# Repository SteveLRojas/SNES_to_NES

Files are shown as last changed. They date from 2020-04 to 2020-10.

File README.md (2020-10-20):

# SNES_to_NES
This project is an adapter board designed to be installed inside a SNES gamepad.  
The source is written in assembly for the AT90S1200 MCU. All code is in the main ASM file.  
All the project details can be inferred from the source file, which is short, simple, and well commented.  
A single layer PCB design is included.  

Bug fix: added temporary nes variable in main. This is need so that the NES variable is always valid, as the NES console can trigger an interrupt and read it at any time.  
	In previous versions the A and B buttons had a small chance of getting pressed at random, which made games such as B-Wings effectively unplayable.  

News update: The AT90S1200 microcontroller used in this project has been obsolete for a very long time (~2004), so I will no longer maintain this project.
A new project has been created using an ATtiny24.

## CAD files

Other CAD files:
SNES_to_NES.obj

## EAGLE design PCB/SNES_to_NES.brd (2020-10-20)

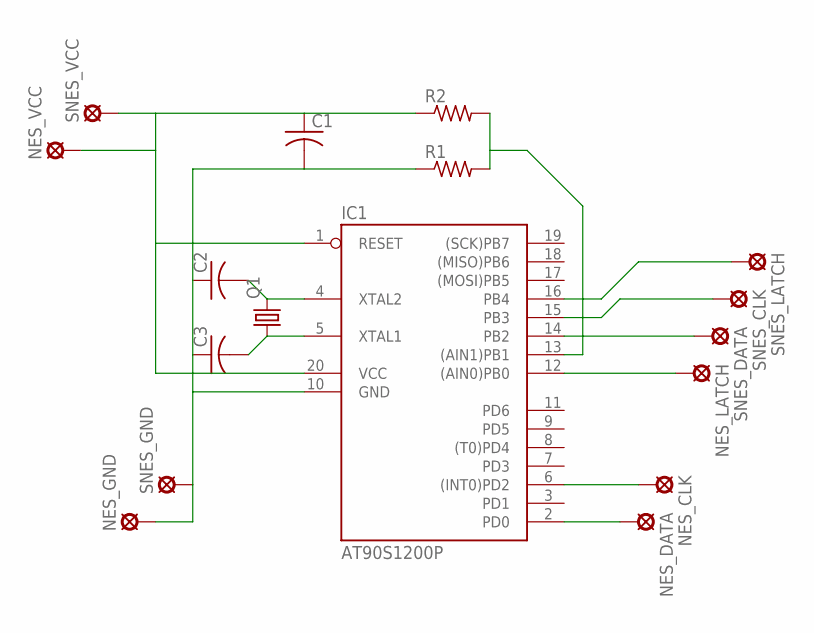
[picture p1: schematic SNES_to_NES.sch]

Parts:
C1: C-US025_050-035X075; C025_050-035X075
C2, C3: C-US025-030X050; C025-030X050
IC1: AT90S1200P; DIL20
NES_CLK: MCS08
NES_DATA: MCS08
NES_GND: MCS08
NES_LATCH: MCS08
NES_VCC: MCS08
Q1: CRYSTALHC49U-H; HC49U-H
R1, R2: R-US_0207/7; 0207/7
SNES_CLK: MCS08
SNES_DATA: MCS08
SNES_GND: MCS08
SNES_LATCH: MCS08
SNES_VCC: MCS08

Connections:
GND: C1.2, C2.1, C3.1, IC1.10 (GND), NES_GND.MP, R1.1, SNES_GND.MP
unnamed: C1.1, IC1.1 (RESET), IC1.20 (VCC), NES_VCC.MP, R2.1, SNES_VCC.MP
unnamed: IC1.15 (PB3), SNES_CLK.MP
unnamed: C3.2, IC1.5 (XTAL1), Q1.1
unnamed: C2.2, IC1.4 (XTAL2), Q1.2
unnamed: IC1.13 ((AIN1)PB1), R1.2, R2.2
unnamed: IC1.16 (PB4), SNES_LATCH.MP
unnamed: IC1.12 ((AIN0)PB0), NES_LATCH.MP
unnamed: IC1.14 (PB2), SNES_DATA.MP
unnamed: IC1.2 (PD0), NES_DATA.MP
unnamed: IC1.6 ((INT0)PD2), NES_CLK.MP

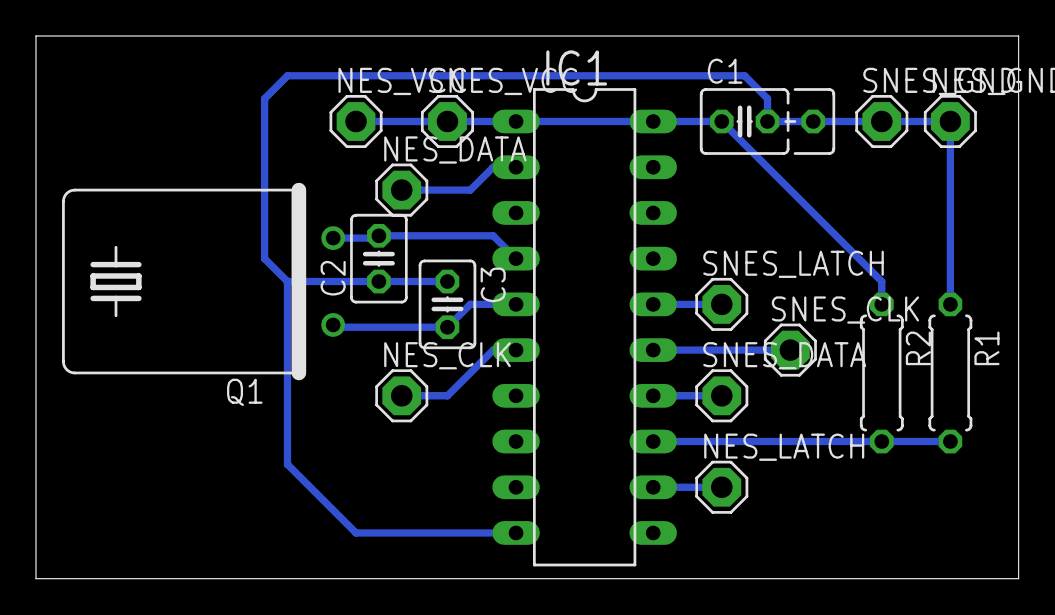
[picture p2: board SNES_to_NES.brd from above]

Board: 2 copper layers, 54.6 x 30.1 mm, 17 parts (0 on the bottom side), 11 nets.

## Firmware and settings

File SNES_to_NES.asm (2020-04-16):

.NOLIST
.INCLUDE "1200def.inc"
.LIST

.DEVICE AT90S1200

.DEF GEN_COUNT = R16	;USED FOR FULLDELAY_232, HLAFDELAY_232
.DEF DREG = R17	;USED TO STORE RECEIVED DATA
.DEF SNES_HIGH = R18
.DEF SNES_LOW = R19
.DEF NES = R20
.DEF MASK = R21
.DEF READ_COUNT = R22
.DEF GEN_COUNT2 = R23
.DEF NES_SHIFT = R24
.DEF NES_TEMP = R25
.EQU fq = 4000000	;XTal frequency definition

; PORT USAGE:
; RXD		PORT D BIT 5	INPUT
; TXD		PORT D BIT 4	OUTPUT
; NES_CLK	PORT D BIT 2	INPUT INTERRUPT
; NES_DATA	PORT D BIT 0	OUTPUT
;SNES_LATCH PORT B BIT 4	OUTPUT
; SNES_CLK	PORT B BIT 3	OUTPUT
; SNES_DATA PORT B BIT 2	INPUT
; ANALOG	PORT B BIT 1	INPUT ALWAYS VCC/2 	THIS IS DONE TO USE PORT B 0 AS AN INTERRUPT SOURCE
; NES LATCH PORT B BIT 0	INPUT INTERRUPT

.CSEG
.ORG $0000
	RJMP	INIT	;RESET VECTOR
	RJMP NES_OUT	;INT0 VECTOR
	RETI	;TIMER/COUNTER OVERFLOW VECTOR
	RJMP NES_LATCH	;ANALOG COMPARATOR VECTOR


INIT:
	LDI DREG, 0b00010001
	OUT DDRD, DREG	;CONFIGURE PORT D
	LDI DREG, 0b00011000
	OUT DDRB, DREG	;CONFIGURE PORT B
	LDI DREG, 0b01000000
	OUT GIMSK, DREG	;ENABLE INT0
	IN DREG, MCUCR
	ORI DREG, 0b00000011
	OUT MCUCR, DREG	;CONFIGURE INT0 FOR RISING EDGE
	LDI DREG, 0b00001011
	OUT ACSR, DREG	;POWER ON THE ANALOG COMPARATOR AND ENABLE THE INTERRUPT
	LDI NES_SHIFT, 0xFF	;CLEAR ALL BUTTONS
	SEI	;ENABLE INTERRUPTS
	RJMP MAIN

NES_OUT:
	CBI PORTD, 0
	SBRC NES_SHIFT, 0
	SBI PORTD, 0	;COPY BIT 0 FROM NES SHIFT TO NES DATA
	LSR NES_SHIFT	;SHIFT NES_SHIFT RIGHT
	RETI

NES_LATCH:
	CBI PORTD, 0
	SBRC NES, 0
	SBI PORTD, 0	;COPY BIT 0 FROM NES TO NES DATA LINE
	MOV NES_SHIFT, NES	;COPY NEW DATA TO SHIFT REGISTER
	LSR NES_SHIFT	;PREPARE NEXT BIT
	RETI

SNES_READ:
	CLR SNES_HIGH
	CLR SNES_LOW
	SBI PORTB, 4	;SET LATCH HIGH
	SBI PORTB, 3	;SET CLK HIGH
	RCALL SNES_DELAY
	CBI PORTB, 4	;CLEAR LATCH
	CBI PORTB, 3	;CLEAR CLK
	RCALL SNES_DELAY
	SBIC PINB, 2	;CHECK SNES DATA
	SBR SNES_LOW, 0B00000001	;SET BIT 0
	
	SBI PORTB, 3	;SET CLK HIGH
	RCALL SNES_DELAY
	CBI PORTB, 3	;CLEAR CLK
	RCALL SNES_DELAY
	SBIC PINB, 2	;CHECK SNES DATA
	SBR SNES_LOW, 0B00000010	;SET BIT 1

	SBI PORTB, 3	;SET CLK HIGH
	RCALL SNES_DELAY
	CBI PORTB, 3	;CLEAR CLK
	RCALL SNES_DELAY
	SBIC PINB, 2	;CHECK SNES DATA
	SBR SNES_LOW, 0B00000100	;SET BIT 2

	SBI PORTB, 3	;SET CLK HIGH
	RCALL SNES_DELAY
	CBI PORTB, 3	;CLEAR CLK
	RCALL SNES_DELAY
	SBIC PINB, 2	;CHECK SNES DATA
	SBR SNES_LOW, 0B00001000	;SET BIT 3

	SBI PORTB, 3	;SET CLK HIGH
	RCALL SNES_DELAY
	CBI PORTB, 3	;CLEAR CLK
	RCALL SNES_DELAY
	SBIC PINB, 2	;CHECK SNES DATA
	SBR SNES_LOW, 0B00010000	;SET BIT 4

	SBI PORTB, 3	;SET CLK HIGH
	RCALL SNES_DELAY
	CBI PORTB, 3	;CLEAR CLK
	RCALL SNES_DELAY
	SBIC PINB, 2	;CHECK SNES DATA
	SBR SNES_LOW, 0B00100000	;SET BIT 5

	SBI PORTB, 3	;SET CLK HIGH
	RCALL SNES_DELAY
	CBI PORTB, 3	;CLEAR CLK
	RCALL SNES_DELAY
	SBIC PINB, 2	;CHECK SNES DATA
	SBR SNES_LOW, 0B01000000	;SET BIT 6

	SBI PORTB, 3	;SET CLK HIGH
	RCALL SNES_DELAY
	CBI PORTB, 3	;CLEAR CLK
	RCALL SNES_DELAY
	SBIC PINB, 2	;CHECK SNES DATA
	SBR SNES_LOW, 0B10000000	;SET BIT 7

	SBI PORTB, 3	;SET CLK HIGH
	RCALL SNES_DELAY
	CBI PORTB, 3	;CLEAR CLK
	RCALL SNES_DELAY
	SBIC PINB, 2	;CHECK SNES DATA
	SBR SNES_HIGH, 0B00000001	;SET BIT 0

	SBI PORTB, 3	;SET CLK HIGH
	RCALL SNES_DELAY
	CBI PORTB, 3	;CLEAR CLK
	RCALL SNES_DELAY
	SBIC PINB, 2	;CHECK SNES DATA
	SBR SNES_HIGH, 0B00000010	;SET BIT 1

	SBI PORTB, 3	;SET CLK HIGH
	RCALL SNES_DELAY
	CBI PORTB, 3	;CLEAR CLK
	RCALL SNES_DELAY
	SBIC PINB, 2	;CHECK SNES DATA
	SBR SNES_HIGH, 0B00000100	;SET BIT 2

	SBI PORTB, 3	;SET CLK HIGH
	RCALL SNES_DELAY
	CBI PORTB, 3	;CLEAR CLK
	RCALL SNES_DELAY
	SBIC PINB, 2	;CHECK SNES DATA
	SBR SNES_HIGH, 0B00001000	;SET BIT 3

	SBI PORTB, 3	;SET CLK HIGH
	RCALL SNES_DELAY
	CBI PORTB, 3	;CLEAR CLK
	RCALL SNES_DELAY
	SBIC PINB, 2	;CHECK SNES DATA
	SBR SNES_HIGH, 0B00010000	;SET BIT 4

	SBI PORTB, 3	;SET CLK HIGH
	RCALL SNES_DELAY
	CBI PORTB, 3	;CLEAR CLK
	RCALL SNES_DELAY
	SBIC PINB, 2	;CHECK SNES DATA
	SBR SNES_HIGH, 0B00100000	;SET BIT 5

	SBI PORTB, 3	;SET CLK HIGH
	RCALL SNES_DELAY
	CBI PORTB, 3	;CLEAR CLK
	RCALL SNES_DELAY
	SBIC PINB, 2	;CHECK SNES DATA
	SBR SNES_HIGH, 0B01000000	;SET BIT 6

	SBI PORTB, 3	;SET CLK HIGH
	RCALL SNES_DELAY
	CBI PORTB, 3	;CLEAR CLK
	RCALL SNES_DELAY
	SBIC PINB, 2	;CHECK SNES DATA
	SBR SNES_HIGH, 0B10000000	;SET BIT 7
	RET

MAIN:
	RCALL SNES_READ
	MOV NES_TEMP, SNES_LOW	;MOST BITS ARE THE SAME IN NES AND SNES
	ANDI NES_TEMP, 0B11111100	;BUT THE LOW 2 BITS ARE DIFFERENT
	SBRC SNES_HIGH, 0	;CHECK BIT 0 IN SNES HIGH
	ORI NES_TEMP, 0B00000001	;IF BIT 0 IN SNES IS SET THEN SET BIT 0 IN NES
	SBRC SNES_LOW, 0
	ORI NES_TEMP, 0B00000010	;IF BIT 0 IN SNES LOW IS SET THEN SET BIT 1 IN NES
	EOR NES_TEMP, MASK	;MODIFY A AND B
	SBRS SNES_HIGH, 3	;CHECK THE RIGHT BUTTON
	RCALL KONAMI	;IF RIGHT BUTTON IS PRESSED CALL KONAMI MACRO
	SBRS SNES_HIGH, 2	;CHECK THE LEFT BUTTON
	ANDI NES_TEMP, 0b11111110	;IF LEFT BUTTON IS PRESSED THEN PRESS BUTTON A IN NES
	INC READ_COUNT
	;CPI READ_COUNT, 0x80
	;BRNE M_NO_RESET
	;CLR READ_COUNT
;M_NO_RESET:
	CLR MASK
	SBRC SNES_HIGH, 1	;CHECK X BUTTON IN SNES
	RJMP NO_X
	ORI MASK, 0B00000001	;INVERT BUTTON A IN NES
NO_X:
	SBRC SNES_LOW, 1	;CHECK Y BUTTON IN SNES
	RJMP MAIN_TOGGLE
	ORI MASK, 0B00000010	;INVERT BUTTIN B IN NES
MAIN_TOGGLE:
	SBRC READ_COUNT, 7
	CLR MASK	;IF BIT 7 IN READ COUNT IS SET THEN CLEAR MASK
	MOV NES, NES_TEMP	;UPDATE NES REGISTER
	RJMP MAIN

KONAMI:
	LDI NES, 0b11101111	;PRESS UP
	RCALL LONG_DELAY
	LDI NES, 0xFF	;CLEAR ALL BUTTONS
	RCALL LONG_DELAY
	LDI NES, 0b11101111	;PRESS UP
	RCALL LONG_DELAY
	LDI NES, 0xFF	;CLEAR ALL BUTTONS
	RCALL LONG_DELAY
	LDI NES, 0b11011111	;PRESS DOWN
	RCALL LONG_DELAY
	LDI NES, 0xFF	;CLEAR ALL BUTTONS
	RCALL LONG_DELAY
	LDI NES, 0b11011111	;PRESS DOWN
	RCALL LONG_DELAY
	LDI NES, 0xFF	;CLEAR ALL BUTTONS
	RCALL LONG_DELAY
	LDI NES, 0b10111111	;PRESS LEFT
	RCALL LONG_DELAY
	LDI NES, 0xFF	;CLEAR ALL BUTTONS
	RCALL LONG_DELAY
	LDI NES, 0b01111111	;PRESS RIGHT
	RCALL LONG_DELAY
	LDI NES, 0xFF	;CLEAR ALL BUTTONS
	RCALL LONG_DELAY
	LDI NES, 0b10111111	;PRESS LEFT
	RCALL LONG_DELAY
	LDI NES, 0xFF	;CLEAR ALL BUTTONS
	RCALL LONG_DELAY
	LDI NES, 0b01111111	;PRESS RIGHT
	RCALL LONG_DELAY
	LDI NES, 0xFF	;CLEAR ALL BUTTONS
	RCALL LONG_DELAY
	LDI NES, 0b11111101	;PRESS B
	RCALL LONG_DELAY
	LDI NES, 0xFF	;CLEAR ALL BUTTONS
	RCALL LONG_DELAY
	LDI NES, 0b11111110	;PRESS A
	RCALL LONG_DELAY
	LDI NES, 0xFF	;CLEAR ALL BUTTONS
	RET
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

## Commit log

2020-04-16 bug fix
    [SNES_to_NES.obj]
2020-10-20 Added PCB files
    [SNES_to_NES.brd, SNES_to_NES.sch]
